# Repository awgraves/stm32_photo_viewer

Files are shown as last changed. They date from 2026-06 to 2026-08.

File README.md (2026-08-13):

# STM32 Photo Viewer
A picture-frame-like embedded device that renders photos from a micro SD card.

STM32 Photo Viewer Demo

Firmware written 100% by hand from scratch. ✍️
- ❌ No generated code
- ❌ No 3rd party frameworks or libraries
- ❌ No vendor HAL (hardware abstraction layer), not even CMSIS headers
- ✅ Linker script, vector table, reset handler, clock trees, all manually set up
- ✅ GPIO, SPI, SDIO, TIMER, DMA drivers from the ground up
- ✅ Custom lightweight graphics utilities
- ✅ Hand-rolled SD card driver with a minimal FAT32 reader

And for the physical device:
- ✅ Custom PCB design using EasyEDA + JLCPCB as manufacturer
- ✅ 3D printed case on a Bambu Lab A1 mini

Watch the project build video on YouTube 👇

STM32 Photo Viewer - From Start to Finish (https://www.youtube.com/watch?v=W2JZO2xCuKY)

## Features
- Handles up to ***5,000 photos*** at a time
- Manual photo browse mode
- Slideshow modes with 2, 5, or 10 second intervals
- Adjustable display brightness

## Hardware
- STM32F446RE (32-bit Arm Cortex M4 processor)
- [3.5" TFT LCD display w/ ST7796 controller](https://www.amazon.com/dp/B0DFWL9M9B)
- [EC11 rotary encoder](https://www.amazon.com/dp/B0DZTX96NH)
- SD card slot (during initial prototyping, used the [Adafruit breakout module](https://www.adafruit.com/product/4682))

## Schematics
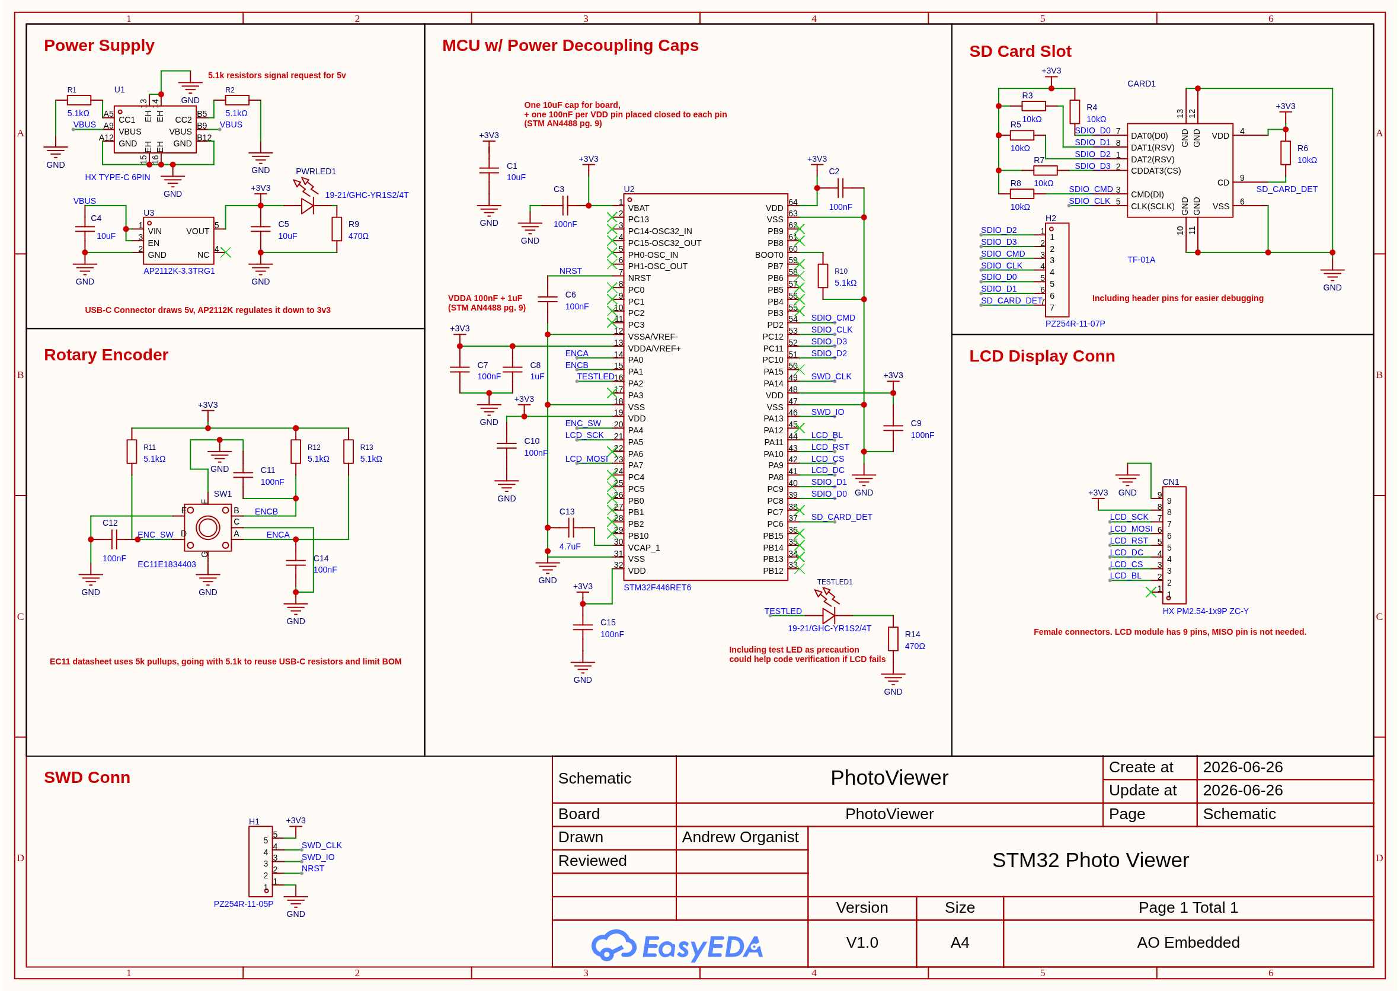
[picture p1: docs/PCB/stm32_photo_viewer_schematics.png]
EasyEDA Board Schematics


## Requirements
1. [GNU Arm Embedded Toolchain](https://developer.arm.com/downloads/-/gnu-rm)
2. [GNU Make](https://www.gnu.org/software/make/)
3. [Bear](https://github.com/rizsotto/Bear) for clangd compile_commands generation
4. [OpenOCD](https://openocd.org/pages/getting-openocd.html) for ST-link connection
5. [GDB](https://www.sourceware.org/gdb/) (optional)
6. [UV Python package & project manager](https://docs.astral.sh/uv/) for photo conversion script

## Loading Photos
A high capacity micro SD card is required and must be pre-formatted to contain a FAT32 filesystem located at the 1st partition.

The firmware expects photos to be in the root dir of the FS in a `.pic` binary file format. 

A photo conversion script is included under `tools/convert.py`.
See the tool [README](tools/README.md) for more details.

## Local Dev
1. Run `make setup` to generate the clangd compile commands for your IDE.
2. `make flash` will flash the code to the board.

## Debugging
1. `make debug_server` will start an openocd connection to the board.
2. Once the connection is open, in a separate terminal, run the `make debug` command to begin a GDB session.

## RAM Budgeting
### Total RAM available
On STM32F446RE: **128KB**

### Noteworthy Buffer Allocations
- Photo rendering: 64KB (50% of total RAM)
- File list: ~39KB (~30%), translates to max 5000 photos
- Graphics rendering: 10KB (~8%)

Leaves 15KB remaining for stack + plenty of head room (~12%)

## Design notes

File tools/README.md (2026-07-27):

# Photo Conversion

## What is it and why?
Image formats can be pretty complicated, especially with compression used in modern JPEG and PNG files.

Since I wanted to write 100% of the firmware by hand, I opted not to go down the complicated rabbit hole of image decompression logic.

Instead, I wrote a simple PC-side utility script in Python that only needs to be run once on a batch of photos before copying them over to the SD card.

The '.pic' custom file format is a simple as it gets: just **raw left->right, top->bottom RGB565 pixel data in BIG endian format that matches the height/width dimensions of the LCD display exactly**.

This simplifies the firmware logic to:
1. Opening a .pic file
2. Directly streaming the byte contents *as-is* over the SPI wires to the display

And avoids:
1. image decompression
2. dynamic height/width resizing
3. endianness swap (little endian on SD card / ARM Cortex CPU but big endian required over the SPI wire)

## Directions
1. Create a subdir here in the same dir as this README called 'inputs' and place any desired photos in there.
2. From project root, run `make convert` which will dump converted files into an 'outputs' subdir under /tools.
3. Copy the outputs subdir contents directly onto the root dir of the SD card.

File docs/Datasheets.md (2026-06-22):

# Datasheet / Reference manual links

1. STM32 NUCLEO-F446RE board user manual: https://www.st.com/resource/en/user_manual/um1724-stm32-nucleo64-boards-mb1136-stmicroelectronics.pdf

2. STM32 F446RE datasheet: https://www.st.com/resource/en/datasheet/stm32f446mc.pdf

3. STM32 Reference Manual (RM0390): https://www.st.com/resource/en/reference_manual/rm0390-stm32f446xx-advanced-armbased-32bit-mcus-stmicroelectronics.pdf

4. ARM cortex-M4 general manual: https://www.manualslib.com/manual/1231314/Arm-Cortex-M4.html

Electronic parts:
1. https://www.diodes.com/assets/Datasheets/AP2112.pdf

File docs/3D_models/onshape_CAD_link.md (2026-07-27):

# CAD Project Link

[OnShape 3D Printed Case Designs Link](https://cad.onshape.com/documents/46d03b8d4aa22f986552a5a5/w/ad2c834649631efe00d3863d/e/dfbb95d2304457098090e84b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)

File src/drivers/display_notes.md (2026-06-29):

# Notes from the docs
ILI9341 and ST7796 LCD drivers both share essentially the same commands.
The differences lie in the height/width and desired portrait vs landscape orientation.

## ST7796 documentation
https://www.displayfuture.com/Display/datasheet/controller/ST7796s.pdf

## Waveshare documentation
https://www.waveshare.com/wiki/2.4inch_LCD_Module#Introduction

### Hardware Description
Supports 12, 16, 18 bit input colors
aka RGB444, RGB565, RGB666
uses four-wire SPI

### Communication Protocol
Pins:
- No MISO, because display is read only
- RESX: reset, low when powering up, high at other times
- CS: chip select, low = enabled
- DC: 0 = command 1 = data

Clock polarity = 0 (idle low)
Clock phase = 0 (first clock edge)

## ILI9341
https://files.waveshare.com/upload/e/e3/ILI9341_DS.pdf

### Serial Interface
pg. 33, 4-line/8-bit setup

1. D/CX: data/command selection
2. CSX: chip enable input
3. SCL: serial clock
4. SDA/SDI/SDO: serial data i/o (DIN in this case)

SCL can be stopped when no comm necessary

MSB is transmitted first

pg. 63 shows RGB565 on 4 wire setup
RGB565 gives 65k colors with 16-bits
RGB666 gives 262K colors with 18-bits

### Command list
begins pg. 83
- nop: (0x00) can be used to terminate frame memory write / read pg. 89
- softare reset: (0x01) pg. 90
- sleep OUT: (0x11) pg. 101
  - on initial power on, will be in sleep IN mode
  - requires 120ms wait time
- display off: (0x28) pg. 108
- display on: (0x29) pg. 109
- memory write: (0x2C) pg. 114
- color set: (0x2D), not sure if needed? pg. 115
- write display brightness: (0x51) pg. 141
- Pixel Format Set: (0x3A) pg. 134
  - follow with a paramater (data mode!) 01010101 ie 0x55 for 16 bit pixels
- RGB interface control: (0x0H) pg. 154
  - pg. 45 describes more

### Memory read/write
Diagram data stream is from left to right, top left is 0,0 pg. 207

### Reset Sequence
pg. 213, should plan for case 1 - RST pin high/unstable on power on
sleep out (aka come out of sleep mode) takes 120ms

pg. 217, power on starts in sleep IN mode

### Timing diagram
pg. 237
Clock cycle min duration 40ns (aka max clock speed is 25MHz)

Initialization:
1. hardware reset (with RST pin held low, then high)
2. software reset with 0x01 command
3. set SLEEP to out
4. set pixel format
5. display on

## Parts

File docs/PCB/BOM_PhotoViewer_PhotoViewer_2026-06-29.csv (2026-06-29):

No. | Quantity | Comment | Designator | Footprint | Value | Manufacturer Part | Manufacturer | Supplier Part | Supplier
1 | 1 | 10uF | C1 | C0603 | 10uF | CL10A106KP8NNNC | SAMSUNG(三星) | C19702 | LCSC
2 | 10 | 100nF | C2,C3,C6,C7,C9,C10,C11,C12,C14,C15 | C0402 | 100nF | CL05B104KO5NNNC | SAMSUNG(三星) | C1525 | LCSC
3 | 2 | 10uF | C4,C5 | C0805 | 10uF | CL21A106KAYNNNE | SAMSUNG(三星) | C15850 | LCSC
4 | 1 | 1uF | C8 | C0402 | 1uF | CL05A105KA5NQNC | SAMSUNG(三星) | C52923 | LCSC
5 | 1 | 4.7uF | C13 | C0402 | 4.7uF | CL05A475MP5NRNC | SAMSUNG(三星) | C23733 | LCSC
6 | 1 | TF-01A | CARD1 | TF-SMD_TF-01A |  | TF-01A | 韩国韩荣 | C91145 | LCSC
7 | 1 | HX PM2.54-1x9P ZC-Y | CN1 | HDR-TH_9P-P2.54-V-F-1 |  | HX PM2.54-1x9P ZC-Y | hanxia(韩下) | C22438159 | LCSC
8 | 1 | PZ254R-11-05P | H1 | HDR-TH_5P-P2.54-H-M-W10.4 |  | PZ254R-11-05P | XFCN(兴飞) | C492413 | LCSC
9 | 1 | PZ254R-11-07P | H2 | HDR-TH_7P-P2.54-H-M-W10.4 |  | PZ254R-11-07P | XFCN(兴飞) | C492415 | LCSC
10 | 2 | 19-21/GHC-YR1S2/4T | PWRLED1,TESTLED1 | LED0603-R-RD |  | 19-21/GHC-YR1S2/4T | EVERLIGHT(亿光) | C2986048 | LCSC
11 | 6 | 5.1kΩ | R1,R2,R10,R11,R12,R13 | R0402 | 5.1kΩ | 0402WGF5101TCE | UNI-ROYAL(厚声) | C25905 | LCSC
12 | 6 | 10kΩ | R3,R4,R5,R6,R7,R8 | R0805 | 10kΩ | 0805W8F1002T5E | UNI-ROYAL(厚声) | C17414 | LCSC
13 | 2 | 470Ω | R9,R14 | R0603 | 470Ω | 0603WAF4700T5E | UNI-ROYAL(厚声) | C23179 | LCSC
14 | 1 | EC11E1834403 | SW1 | SW-TH_EC11E1820402 |  | EC11E1834403 | ALPSALPINE(阿尔卑斯阿尔派) | C361165 | LCSC
15 | 1 | HX TYPE-C 6PIN | U1 | USB-C-SMD_HX-TYPE-C-6PIN |  | HX TYPE-C 6PIN | hanxia(韩下) | C18357552 | LCSC
16 | 1 | STM32F446RET6 | U2 | LQFP-64_L10.0-W10.0-P0.50-LS12.0-BL |  | STM32F446RET6 | ST(意法半导体) | C69336 | LCSC
17 | 1 | AP2112K-3.3TRG1 | U3 | SOT-23-5_L2.9-W1.6-P0.95-LS2.8-BR |  | AP2112K-3.3TRG1 | TECH PUBLIC(台舟) | C23380830 | LCSC

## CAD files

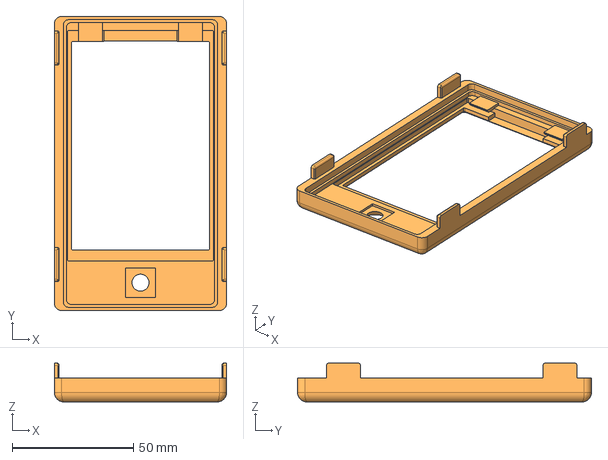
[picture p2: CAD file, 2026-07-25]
docs/3D_models/Case Front.step
71.2 x 121.4 x 16.1 mm

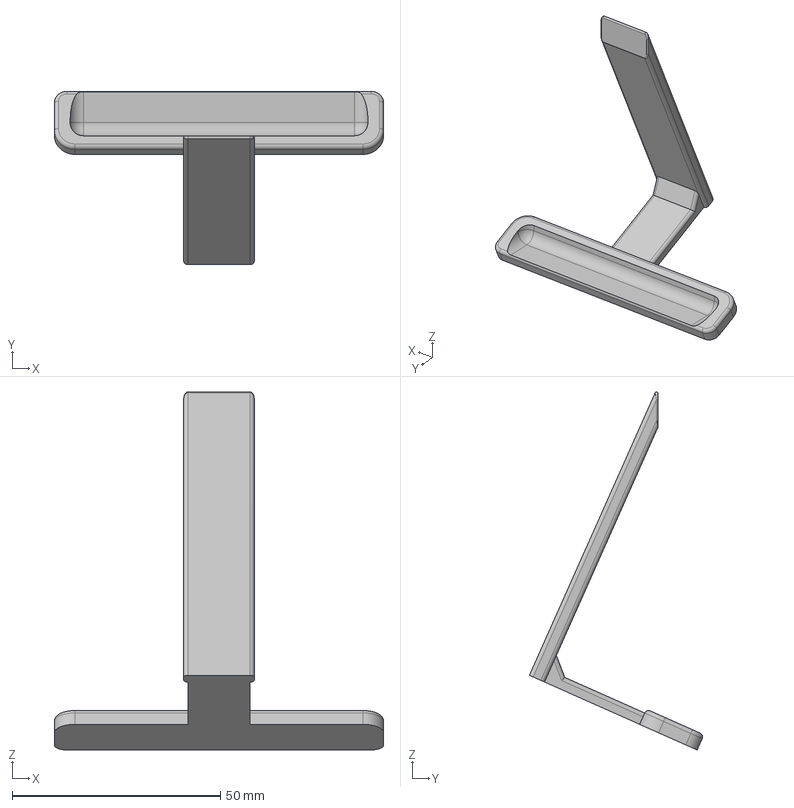
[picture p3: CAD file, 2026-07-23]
docs/3D_models/Case Stand.step
79.2 x 41.6 x 86.0 mm

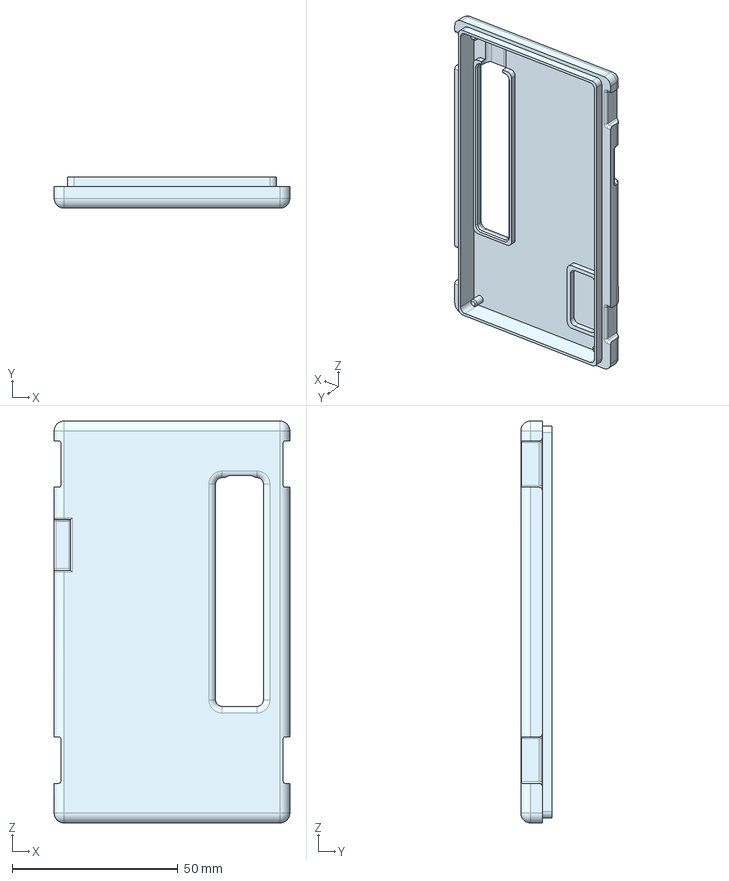
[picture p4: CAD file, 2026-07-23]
docs/3D_models/Case Back.step
71.2 x 9.50 x 121.4 mm

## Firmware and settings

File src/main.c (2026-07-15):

#include "board/board.h"
#include "drivers/time.h"
#include "events/event_queue.h"
#include "inputs/poll.h"
#include "screens/screens.h"
#include "screens/splash.h"
#include "slideshow/slideshow.h"
#include "storage/storage.h"

#define POLL_MS_INTERVAL 5 // fine enough that UI lag is imperceptible

void process_events(void);
screen_t *curr_screen;

int main() {
  board_init();

  splash_show();

  curr_screen = &init;
  curr_screen->enter();

  uint32_t last_poll = 0;
  uint32_t now = 0;
  while (1) {
    now = millis();
    if (now - last_poll >= POLL_MS_INTERVAL) {
      last_poll = now;
      storage_poll();
      inputs_poll();
      slideshow_poll();
      process_events();
    }
  }
}

void process_events(void) {
  event_t event;
  screen_t *next;
  while (event_queue_pop(&event)) {
    next = curr_screen->handle_event(event);
    if (next != curr_screen) {
      curr_screen->exit();
      curr_screen = next;
      curr_screen->enter();
    }
  }
}

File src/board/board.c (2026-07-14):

#include "board.h"
#include "drivers/display.h"
#include "drivers/rotary_encoder.h"
#include "drivers/sd_card.h"
#include "mcu/spi.h"
#include "mcu/sysclock.h"
#include "mcu/systick.h"

#define LCD_SPI_SCK PA5
#define LCD_SPI_MOSI PA7
#define LCD_CS PA9
#define LCD_DC PA8
#define LCD_RST PA10
#define LCD_BL PA11 // TIM1_CH4, datasheet pg 53

#define ENC_A PA0 // TIM2_CH1 AF datasheet pg 47
#define ENC_B PA1 // TIM2_CH2 AF datasheet pg 47
#define ENC_CENTER PA4

// datasheet AF table pg. 59-60
#define SDIO_D0 PC8
#define SDIO_D1 PC9
#define SDIO_D2 PC10
#define SDIO_D3 PC11
#define SDIO_CLK PC12
#define SDIO_CMD PD2
#define SD_DET PC6

/*
Note that SWDIO is on PA13
and SWDCLK is on PA14

also note nucleo board manual pg. 36 for board pin layout
*/

/*
  See the SPEED_PROFILE var in the makefile.
  Slower speed useful for bring up on a dev board with long wires,
  Fast speed works great on a PCB with short traces.
*/
#if defined(SPEED_PROFILE_FAST)
#define CPU_FREQ CPU_FREQ_168_MHZ
#define SPI_BAUD_DIV SPI_BAUD_DIV_2
#define SPI_GPIO_SPEED GPIO_SPEED_FAST
#elif defined(SPEED_PROFILE_SLOW)
#define CPU_FREQ CPU_FREQ_32_MHZ
#define SPI_BAUD_DIV SPI_BAUD_DIV_2
#define SPI_GPIO_SPEED GPIO_SPEED_SLOW
#endif

void board_init(void) {
  sysclock_init(CPU_FREQ);
  systick_init();

  /* Peripherals */
  spi_config_t spi1_conf = {.mosi = LCD_SPI_MOSI,
                            .sck = LCD_SPI_SCK,
                            .baud = SPI_BAUD_DIV,
                            .gpio_speed = SPI_GPIO_SPEED};
  spi_init(&spi1, &spi1_conf);

  /* Drivers */
  display_config_t display_conf = {.spi = &spi1,
                                   .timer = &timer1,
                                   .bl_af = GPIO_AF_TIM1_TIM2,
                                   .brightness_val = 50,
                                   .cs = LCD_CS,
                                   .dc = LCD_DC,
                                   .rst = LCD_RST,
                                   .bl = LCD_BL};
  display_init(&display_conf);

  rotary_encoder_config_t rot_conf = {.sw1 = ENC_CENTER,
                                      .enca = ENC_A,
                                      .encb = ENC_B,
                                      .enc_af = GPIO_AF_TIM1_TIM2,
                                      .timer = &timer2};
  rotary_encoder_init(&rot_conf);

  sd_card_gpio_config_t sd_conf = {.det = SD_DET,
                                   .sdio = {
                                       .d0 = SDIO_D0,
                                       .d1 = SDIO_D1,
                                       .d2 = SDIO_D2,
                                       .d3 = SDIO_D3,
                                       .clk = SDIO_CLK,
                                       .cmd = SDIO_CMD,
                                   }};
  sd_card_gpio_init(&sd_conf);
}

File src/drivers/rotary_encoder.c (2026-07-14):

#include "rotary_encoder.h"
#include "mcu/timer.h"
#include "time.h"

#define SWITCH_DEBOUNCE_MS 5
#define ENCODER_PULSES_PER_DETENT 4

typedef struct {
  // switch
  gpio_pin_t sw1;
  gpio_digital_t sw_state_stable;
  gpio_digital_t sw_state_last_sample;
  uint32_t sw_last_change_tick;

  // rotary
  timer_t *timer;
  uint16_t last_timer_cnt;
} io_t;

static io_t io;

void rotary_encoder_init(rotary_encoder_config_t *config) {
  io.sw1 = config->sw1;
  io.sw_state_stable = HIGH;
  io.sw_state_last_sample = HIGH;
  io.sw_last_change_tick = millis();
  io.timer = config->timer;
  io.last_timer_cnt = timer_get_cnt(config->timer);

  gpio_set_mode(config->sw1, GPIO_MODE_INPUT);
  gpio_set_mode(config->enca, GPIO_MODE_AF);
  gpio_set_mode(config->encb, GPIO_MODE_AF);

  gpio_set_AF(config->enca, config->enc_af);
  gpio_set_AF(config->encb, config->enc_af);

  gpio_set_pupd(config->sw1, GPIO_PUPD_PULL_UP);
  gpio_set_pupd(config->enca, GPIO_PUPD_PULL_UP);
  gpio_set_pupd(config->encb, GPIO_PUPD_PULL_UP);

  timer_init_in_encoder_mode(io.timer);
}

static bool rotary_encoder_button_poll(void);

rotary_state_t rotary_encoder_get_state(void) {
  uint16_t curr_cnt = timer_get_cnt(io.timer);
  int16_t raw_delta = curr_cnt - io.last_timer_cnt;

  // only register detents (full 'click') as a movement
  int16_t detents = raw_delta / ENCODER_PULSES_PER_DETENT;
  if (detents != 0) {
    io.last_timer_cnt += detents * ENCODER_PULSES_PER_DETENT;
  }

  rotary_state_t state = {.delta = detents,
                          .button_pressed = rotary_encoder_button_poll()};

  return state;
}

/*
  Helpers
*/

static bool rotary_encoder_button_poll(void) {
  gpio_digital_t curr = gpio_digital_read(io.sw1);
  uint32_t now = millis();

  if (curr != io.sw_state_last_sample) {
    io.sw_state_last_sample = curr;
    io.sw_last_change_tick = now;
  }

  if ((now - io.sw_last_change_tick) >= SWITCH_DEBOUNCE_MS) {
    io.sw_state_stable = io.sw_state_last_sample;
  }

  // active low
  return (io.sw_state_stable == LOW);
}

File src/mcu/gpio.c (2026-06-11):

#include "gpio.h"
#include "registers.h"

#define PORT(enum_val)                                                         \
  (GPIO_t *)(((enum_val >> 4) * GPIO_PORT_OFFSET) + GPIOx_BASE)

static inline void gpio_enable_clock(gpio_pin_t pin) {
  // RM0390 pg. 143, GPIOA is bit 0, GPIOB is bit 1, etc
  RCC->AHB1ENR |= (BIT((pin >> 4) & 0xF));
}

void gpio_set_mode(gpio_pin_t pin, gpio_mode_t mode) {
  GPIO_t *port = PORT(pin);
  gpio_enable_clock(pin);

  port->MODER &= ~(3U << (2 * PINNO(pin)));
  port->MODER |= (mode << (2 * PINNO(pin)));
}

void gpio_set_AF(gpio_pin_t pin, gpio_af_t af) {
  GPIO_t *port = PORT(pin);
  uint8_t pinno = PINNO(pin);

  if (pinno < 8) {
    port->AFRL &= ~(0xFU << (4 * pinno));
    port->AFRL |= ((af & 0xFU) << (4 * pinno));
  } else {
    port->AFRH &= ~(0xF << (4 * (pinno - 8)));
    port->AFRH |= ((af & 0xFU) << (4 * (pinno - 8)));
  }
}

// when running higher CPU freq, sometimes need more aggressive signal change
void gpio_set_ospeed(gpio_pin_t pin, gpio_speed_t speed) {
  GPIO_t *port = PORT(pin);
  uint8_t pinno = PINNO(pin);

  port->OSPEEDER &= ~((0x3) << (2 * pinno));
  port->OSPEEDER |= ((speed & 0x3) << (2 * pinno));
}

void gpio_set_pupd(gpio_pin_t pin, gpio_pupdr_t pupdr) {
  GPIO_t *port = PORT(pin);
  uint8_t pinno = PINNO(pin);

  port->PUPDR &= ~((0x3) << (2 * pinno));
  port->PUPDR |= ((pupdr & 0x3) << (2 * pinno));
}

void gpio_set_pin(gpio_pin_t pin) {
  GPIO_t *port = PORT(pin);
  port->BSRR = (1U << PINNO(pin));
}

void gpio_clear_pin(gpio_pin_t pin) {
  GPIO_t *port = PORT(pin);
  port->BSRR = (1U << (PINNO(pin) + 16));
}

void gpio_digital_write(gpio_pin_t pin, gpio_digital_t val) {
  val ? gpio_set_pin(pin) : gpio_clear_pin(pin);
}

gpio_digital_t gpio_digital_read(gpio_pin_t pin) {
  GPIO_t *port = PORT(pin);
  uint8_t pinno = PINNO(pin);

  return port->IDR & (BIT(pinno)) ? HIGH : LOW;
}

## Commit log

2026-05-20 makefile, board bring up, hello world blink
2026-05-22 add systick powered delay functionality
2026-05-23 begin SPI GPIO mappings and document reqs for LCD module
2026-05-24 rename platform to mcu and add board module for pindefs
2026-05-26 confirm SPI1 driver works
2026-05-26 add arduino style digital_write
2026-05-27 ili9341 driver working, basic fill function
2026-05-28 add DMA for SPI
2026-06-08 add exti interrupt support
2026-06-08 add millis function for time comparisons
2026-06-08 barely functional rotary encoder
2026-06-09 improve rotary_encoder by switching to hardware decoding with timer
2026-06-09 clean up main.c, move periph and driver initialization to board_init func
2026-06-11 fix bug with GPIO port offset calc
    [gpio.c, registers.h]
2026-06-12 use proper divisor for 48mhz sysclock & use correct macro to check CFGR changes took effect
    [registers.h]
2026-06-15 add storage abstraction, get basic card status probe working
2026-06-16 refactor sd_card driver to be stateless
2026-06-22 add explicit backlight pin init for backlight
2026-06-22 begin schematic designs
    [photo_viewer.kicad_pcb, photo_viewer.kicad_sch]
2026-06-29 add custom PCB schematics and BOM
    [BOM_PhotoViewer_PhotoViewer_2026-06-29.csv, photo_viewer.kicad_pcb, photo_viewer.kicad_sch]
2026-06-29 decouple display driver impls with compile-time targets
2026-06-30 update rotary encoder logic for ec11 hardware
2026-06-30 switch to time-based button debounce
2026-07-08 invert card detect and encoder direction for new hardware
    [main.c, poll.c, sd_card.c]
2026-07-09 chunk SPI DMA xfers to support larger buffers
2026-07-09 initial pass, functional photo_album with rot encoder next/prev
2026-07-10 bugfix stalled card detect edgecase
    [sdio.c]
2026-07-10 add window and button ui components
2026-07-11 remove filename from file struct, increase file list cap, add PIC ext filtering
2026-07-13 refactor time funcs to the driver layer, prevent mcu exposure at app layer
    [board.c, display.c, main.c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]
2026-07-14 bugfix apb prescalers needed + add PWM support to LCD BL
    [board.c, display.c, registers.h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]
2026-07-14 decrease spi baud for better stability
    [board.c]
2026-07-14 bugfix SPI DMA race condition
    [board.c, spi.c]
2026-07-20 workable 3d print case models
    [Case Back.step, Case Front.step]
2026-07-23 add step files for stand and updated case front plate
    [Case Back.step, Case Front.step, Case Stand.step]
2026-07-25 tweak front case dimensions for snugger fit
    [Case Front.step]
2026-07-25 flip screen for new orientation (now using JST connectors)
    [display.c]
2026-07-27 update README, add pcb gerber files and onshape CAD link
    [BOM_PhotoViewer_PhotoViewer_2026-06-29.csv]
2026-07-27 add progress bar to pic conversion script, switch to 'inputs' as dir name
